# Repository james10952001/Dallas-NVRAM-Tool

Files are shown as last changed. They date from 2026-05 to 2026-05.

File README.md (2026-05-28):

The original intent of this project was to enable bytewise editing of the memory 
and RTC registers of Dallas timekeeping RAM parts used in a lot of older test equipment
such as the DS1644 and DS1742 used in the Tektronix TDS300 and TDS3000 series oscilloscopes.
In the process of implementing that I realized it was trivial to allow reading virtually any
parallel memory device of 32 pins or less and writing to any SRAM or NVRAM so I added support
for other devices I had on hand. 
While it is usually possible to dump the contents of Dallas devices with a TL866 or similar
device programmer, attempting to write to one will stomp on the RTC and status bytes which
can result in the chip's test mode being enabled or other issues. With this you can view and
manipulate individual bytes such as the power on hours of the TDS3000, view and set the 
time/date/day, and activate the test mode while measuring the frequency. I have tried to make
it relatively simple to add support for additional parts and I will try to do so as examples
come into my possession.

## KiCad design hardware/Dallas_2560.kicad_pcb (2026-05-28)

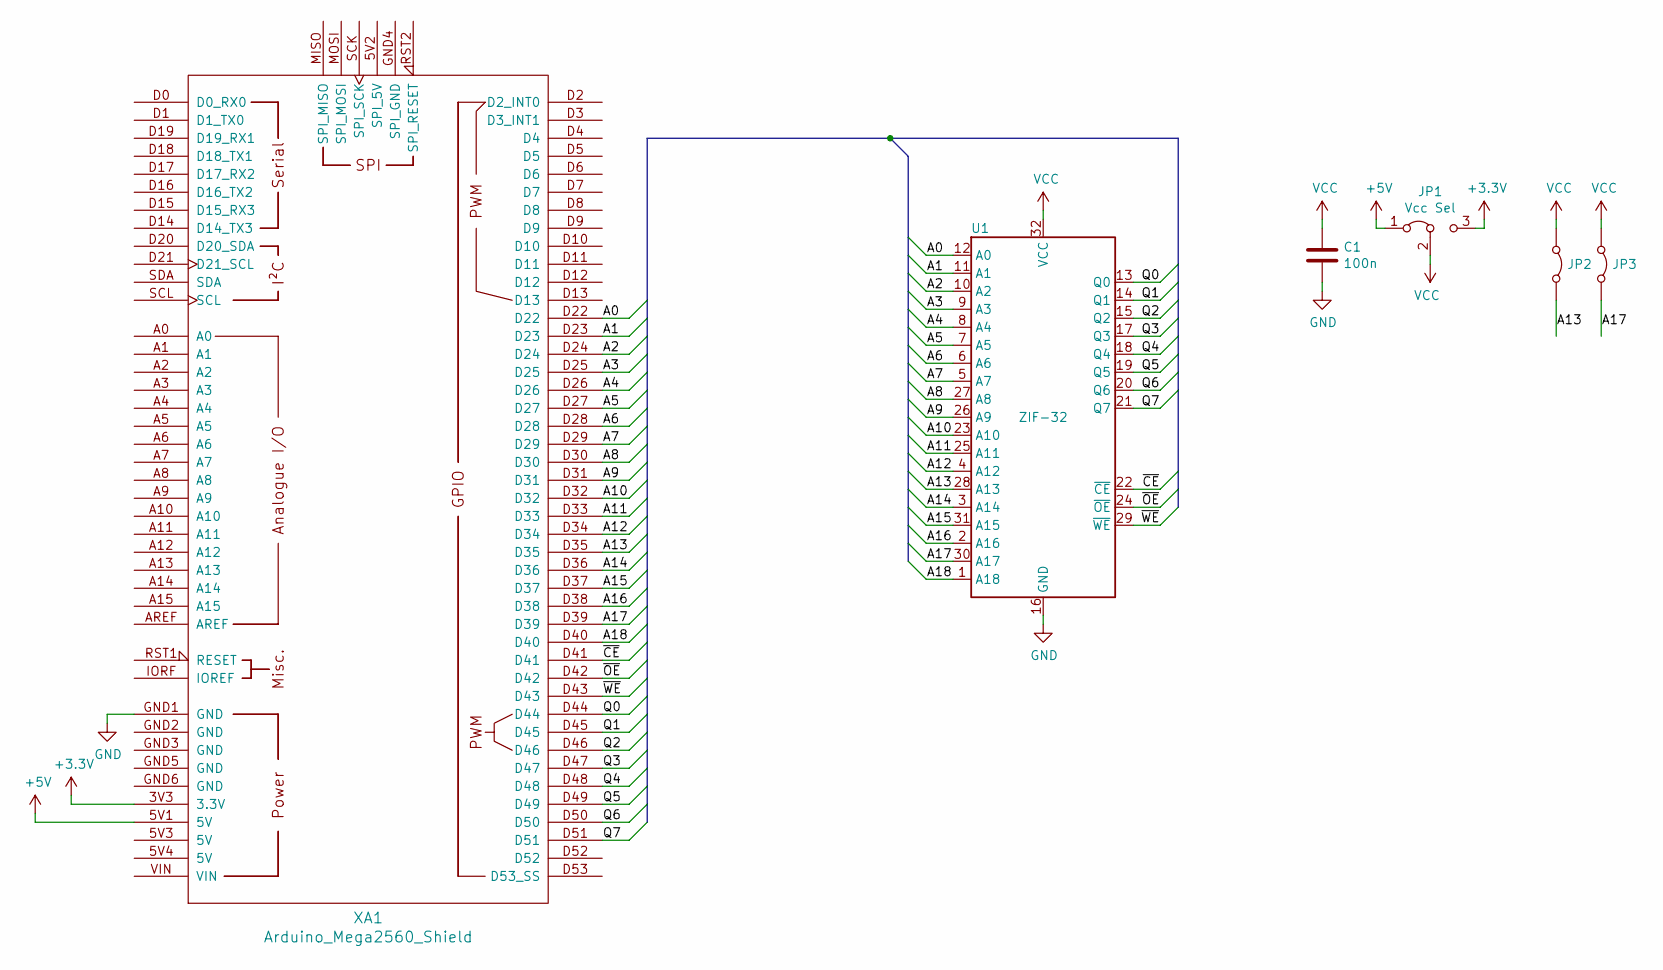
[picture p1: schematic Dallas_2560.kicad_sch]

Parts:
C1: 100n; C_0805_2012Metric
JP1: Vcc Sel; PinHeader_1x03_P2.54mm_Vertical
JP2, JP3: JP; PinHeader_1x02_P2.54mm_Vertical
U1: ZIF-32; DIP_Socket-32_W11.9_W12.7_W15.24_W17.78_W18.5_3M_232-1285-0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
XA1: Arduino_Mega2560_Shield

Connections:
+3V3: JP1.3 (B), XA1.3V3 (3.3V)
+5V: JP1.1 (A), XA1.5V1 (5V)
/A0: U1.12 (A0), XA1.D22
/A1: U1.11 (A1), XA1.D23
/A2: U1.10 (A2), XA1.D24
/A3: U1.9 (A3), XA1.D25
/A4: U1.8 (A4), XA1.D26
/A5: U1.7 (A5), XA1.D27
/A6: U1.6 (A6), XA1.D28
/A7: U1.5 (A7), XA1.D29
/A8: U1.27 (A8), XA1.D30
/A9: U1.26 (A9), XA1.D31
/A10: U1.23 (A10), XA1.D32
/A11: U1.25 (A11), XA1.D33
/A12: U1.4 (A12), XA1.D34
/A13: JP2.2 (B), U1.28 (A13), XA1.D35
/A14: U1.3 (A14), XA1.D36
/A15: U1.31 (A15), XA1.D37
/A16: U1.2 (A16), XA1.D38
/A17: JP3.2 (B), U1.30 (A17), XA1.D39
/A18: U1.1 (A18), XA1.D40
/Q0: U1.13 (Q0), XA1.D44
/Q1: U1.14 (Q1), XA1.D45
/Q2: U1.15 (Q2), XA1.D46
/Q3: U1.17 (Q3), XA1.D47
/Q4: U1.18 (Q4), XA1.D48
/Q5: U1.19 (Q5), XA1.D49
/Q6: U1.20 (Q6), XA1.D50
/Q7: U1.21 (Q7), XA1.D51
/~CE: U1.22 (~CE), XA1.D41
/~OE: U1.24 (~OE), XA1.D42
/~WE: U1.29 (~WE), XA1.D43
GND: C1.2, U1.16 (GND), XA1.GND1 (GND)
VCC: C1.1, JP1.2 (C), JP2.1 (A), JP3.1 (A), U1.32 (VCC)

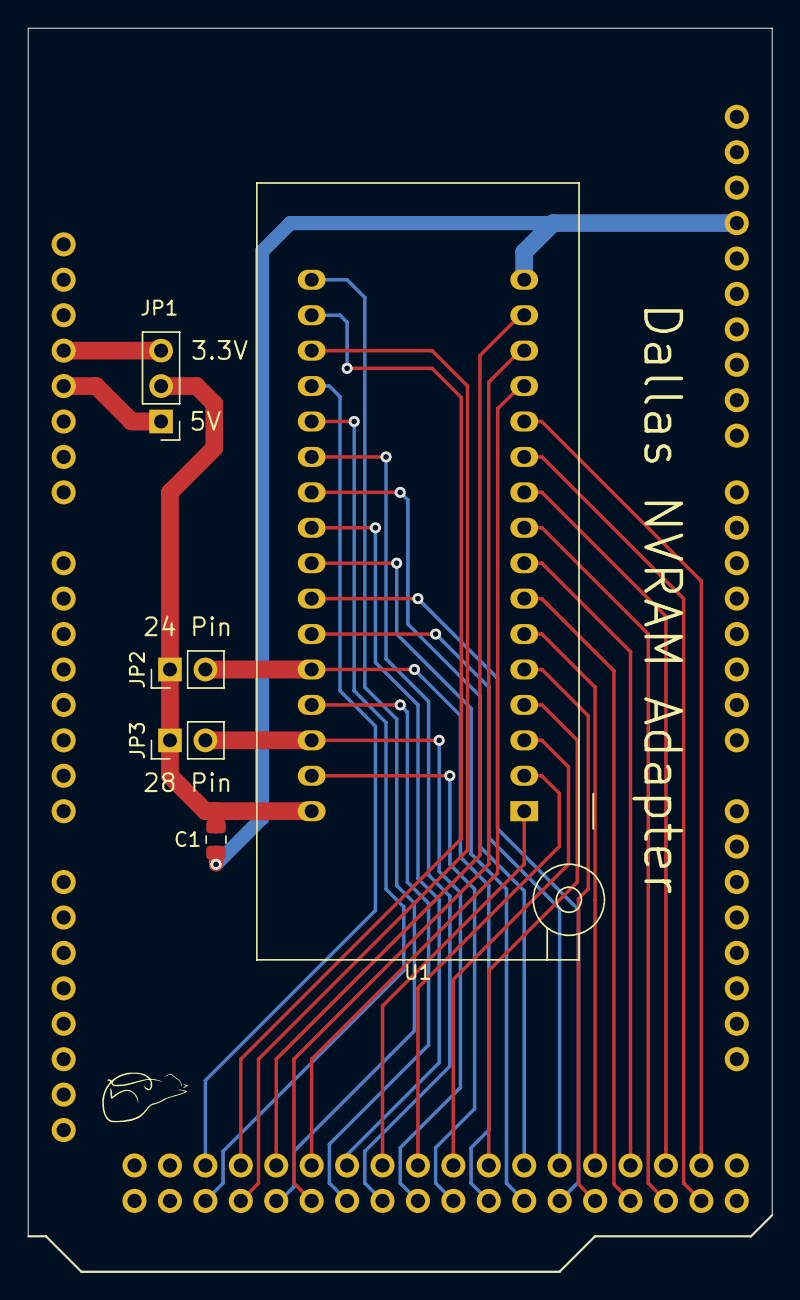
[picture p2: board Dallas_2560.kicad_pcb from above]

Board: 2 copper layers, 53.3 x 89.2 mm, 7 parts (0 on the bottom side), 34 nets.

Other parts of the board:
VAL: REF; cat_300

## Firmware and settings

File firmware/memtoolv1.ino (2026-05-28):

/*
 * Universal NVRAM tool
 *
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
 * You should have received a copy of the GNU General Public License
 * along with this program. If not, see <https://www.gnu.org/licenses/>.
 */

#include <Arduino.h>
#include <EEPROM.h>

const int EEPROM_CONFIG_ADDR = 0;
const int EEPROM_CONFIG_SIZE = 32; // Reserve a generous 32 bytes for future-proofing

// ============================================================
// DEVICE TYPES
// ============================================================

enum DeviceType {
  DEV_GENERIC_24 = 0,
  DEV_GENERIC_28 = 1,
  DEV_GENERIC_32 = 2,
  DEV_DS1742 = 3,
  DEV_DS1644 = 4,
  DEV_KM684000 = 5,
  DEV_MAX // Used strictly for EEPROM boundary validation
};

DeviceType g_device = DEV_DS1742;

// ============================================================
// DYNAMIC PROFILES
// ============================================================

struct PinMap {
  int8_t addr[19]; // Increased from 15 to 19 (A0 - A18) for 512KB chips
  int8_t data[8];  // DQ0 - DQ7
  int8_t ce;
  int8_t oe;
  int8_t we;
  int8_t ce2;      // SECOND Chip Enable (Active HIGH)
};

struct RTCProfile {
  bool hasRTC;
  uint32_t baseAddress; 
  bool hasCentury;     // Does Control register contain Century data?
  bool hasBatteryFlag; // Does Day register contain a Battery Flag?
};

struct DeviceInfo {
  const char* name;
  uint32_t sizeBytes;
  uint32_t protectedStart; 
  RTCProfile rtc;
  PinMap pins;
};

// Global active pin map for fast low-level access
PinMap g_activePins;

// ============================================================
// DEVICE INFO
// ============================================================

// The arduino to 32 pin socket mapping is as follows:
// D40	1
// D38	2
// D36	3
// D34	4
// D29	5
// D28	6
// D27	7
// D26	8
// D25	9
// D24	10
// D23	11
// D22	12
// D44	13
// D45	14
// D46	15
// Gnd	16
// D47	17
// D48	18
// D49	19
// D50	20
// D51	21
// D41	22
// D32	23
// D42	24
// D33	25
// D31	26
// D30	27
// D35	28
// D43	29
// D39	30
// D37	31
// Vcc	32

// Devices smaller than 32 pins are inserted at the lower end of the socket resulting in 
// their pin numbers being offset by 4 for 24 pin devices and 2 for 28 pin devices.


DeviceInfo getDeviceInfo() {
  switch (g_device) {

    case DEV_GENERIC_24:
      return {
        "Generic SRAM/ROM (24 pin)",
        2048,
        0xFFFFFFFF,
        { false, 0, false, false },
        { 
          // A0-A10
          {22, 23, 24, 25, 26, 27, 28, 29, 30, 31, 32, -1, -1, -1, -1, -1, -1, -1, -1}, 
          {44, 45, 46, 47, 48, 49, 50, 51}, 
          41, 42, 33, -1 
        }
      };

    case DEV_GENERIC_28:
      return {
        "Generic SRAM/ROM (28 pin)",
        8192,
        0xFFFFFFFF,
        { false, 0, false, false },
        { 
          // A0-A12
          {22, 23, 24, 25, 26, 27, 28, 29, 30, 31, 32, 33, 34, -1, -1, -1, -1, -1, -1}, 
          {44, 45, 46, 47, 48, 49, 50, 51}, 
          41, 42, 43, 35  // D35 drives CE2 HIGH
        }
      };

    case DEV_GENERIC_32:
      return {
        "Generic SRAM/ROM (32 pin)",
        32768,
        0xFFFFFFFF,
        { false, 0, false, false },
        { 
          // A0-A14
          {22, 23, 24, 25, 26, 27, 28, 29, 30, 31, 32, 33, 34, 35, 36, -1, -1, -1, -1}, 
          {44, 45, 46, 47, 48, 49, 50, 51}, 
          41, 42, 43, -1 
        }
      };

    case DEV_DS1742:
      return {
        "Dallas DS1742",
        2048,
        0x7F8,
        { true, 0x7F8, true, true },
        { 
          // A0-A10
          {22, 23, 24, 25, 26, 27, 28, 29, 30, 31, 32, -1, -1, -1, -1, -1, -1, -1, -1}, 
          {44, 45, 46, 47, 48, 49, 50, 51}, 
          41, 42, 33, -1 
        }
      };

    case DEV_DS1644:
      return {
        "Dallas DS1644",
        32768,
        0x7FF8,
        { true, 0x7FF8, false, false },
        { 
          // A0-A14
          {22, 23, 24, 25, 26, 27, 28, 29, 30, 31, 32, 33, 34, 35, 36, -1, -1, -1, -1}, 
          {44, 45, 46, 47, 48, 49, 50, 51}, 
          41, 42, 43, -1 
        }
      };

    case DEV_KM684000:
      return {
        "Samsung KM684000",
        524288, // 512KB Capacity
        0xFFFFFFFF,
        { false, 0, false, false },
        { 
          // A0-A18 sequential magic!
          {22, 23, 24, 25, 26, 27, 28, 29, 30, 31, 32, 33, 34, 35, 36, 37, 38, 39, 40}, 
          {44, 45, 46, 47, 48, 49, 50, 51}, 
          41, 42, 43, -1 
        }
      };
  }

  // Default fallback (Safe generic 2KB state)
  return {
    "Unknown",
    2048,
    0xFFFFFFFF,
    { false, 0, false, false },
    { 
      {22, 23, 24, 25, 26, 27, 28, 29, 30, 31, 32, -1, -1, -1, -1, -1, -1, -1, -1}, 
      {44, 45, 46, 47, 48, 49, 50, 51}, 
      41, 42, 33, -1 
    }
  };
}

// ============================================================
// RTC BIT DEFINITIONS
// ============================================================

const uint8_t BIT_W   = 0x80;
const uint8_t BIT_R   = 0x40;
const uint8_t BIT_OSC = 0x80;
const uint8_t BIT_FT  = 0x40;
const uint8_t BIT_BF  = 0x80;

// ============================================================
// GLOBALS
// ============================================================

uint8_t g_century = 0;

// ============================================================
// UTILITY FUNCTIONS
// ============================================================

void printHexAddress(uint32_t address) {
  if (address <= 0xFFFF) {
    char buf[5];
    sprintf(buf, "%04lX", address);
    Serial.print(buf);
  } else {
    char buf[9];
    sprintf(buf, "%08lX", address);
    Serial.print(buf);
  }
}

void printHexByte(uint8_t value) {
  if (value < 16) {
    Serial.print('0');
  }
  Serial.print(value, HEX);
}

void print2Digits(uint8_t value) {
  if (value < 10) {
    Serial.print('0');
  }
  Serial.print(value);
}

// ============================================================
// RTC REGISTER HELPERS
// ============================================================

uint32_t regControl() { return getDeviceInfo().rtc.baseAddress + 0; }
uint32_t regSeconds() { return getDeviceInfo().rtc.baseAddress + 1; }
uint32_t regMinutes() { return getDeviceInfo().rtc.baseAddress + 2; }
uint32_t regHours()   { return getDeviceInfo().rtc.baseAddress + 3; }
uint32_t regDay()     { return getDeviceInfo().rtc.baseAddress + 4; }
uint32_t regDate()    { return getDeviceInfo().rtc.baseAddress + 5; }
uint32_t regMonth()   { return getDeviceInfo().rtc.baseAddress + 6; }
uint32_t regYear()    { return getDeviceInfo().rtc.baseAddress + 7; }

// ============================================================
// LOW LEVEL BUS FUNCTIONS
// ============================================================

void applyPinConfiguration() {
  // 1. Reset standard socket pins to INPUT (High-Z) to prevent shorts
  for(uint8_t i = 22; i <= 53; i++) {
     pinMode(i, INPUT);
  }

  // 2. Load the active pin map
  g_activePins = getDeviceInfo().pins;

// 3. Configure Address pins
  for (uint8_t i = 0; i < 19; i++) { // <-- Change to 19
    if (g_activePins.addr[i] != -1) {
      pinMode(g_activePins.addr[i], OUTPUT);
      digitalWrite(g_activePins.addr[i], LOW);
    }
  }

  // 4. Configure Control pins
  pinMode(g_activePins.ce, OUTPUT);
  pinMode(g_activePins.oe, OUTPUT);
  pinMode(g_activePins.we, OUTPUT);
  
  if (g_activePins.ce2 != -1) {
    pinMode(g_activePins.ce2, OUTPUT);
    digitalWrite(g_activePins.ce2, HIGH); // CE2 is active HIGH
  }

  // 5. Secure the bus
  busIdle();
  setDataBusInput();
}

void busIdle() {
  digitalWrite(g_activePins.ce, HIGH);
  digitalWrite(g_activePins.oe, HIGH);
  digitalWrite(g_activePins.we, HIGH);
}

void setAddress(uint32_t address) {
  for (uint8_t i = 0; i < 19; i++) { // <-- Change to 19
    if (g_activePins.addr[i] != -1) {
      digitalWrite(g_activePins.addr[i], (address >> i) & 1);
    }
  }
}

void setDataBusInput() {
  for (uint8_t i = 0; i < 8; i++) {
    pinMode(g_activePins.data[i], INPUT);
  }
}

void setDataBusOutput() {
  for (uint8_t i = 0; i < 8; i++) {
    pinMode(g_activePins.data[i], OUTPUT);
  }
}

void writeDataBus(uint8_t value) {
  for (uint8_t i = 0; i < 8; i++) {
    digitalWrite(g_activePins.data[i], (value >> i) & 1);
  }
}

uint8_t readDataBus() {
  uint8_t value = 0;
  for (uint8_t i = 0; i < 8; i++) {
    if (digitalRead(g_activePins.data[i])) {
      value |= (1 << i);
    }
  }
  return value;
}

// ============================================================
// RAW MEMORY ACCESS
// ============================================================

uint8_t readByteRaw(uint32_t address) {
  busIdle();
  setAddress(address);
  setDataBusInput();
  delayMicroseconds(1);
  digitalWrite(g_activePins.ce, LOW);
  digitalWrite(g_activePins.oe, LOW);
  delayMicroseconds(2);
  uint8_t value = readDataBus();
  busIdle();
  return value;
}

void writeByteRaw(uint32_t address, uint8_t value) {
  busIdle();
  setAddress(address);
  digitalWrite(g_activePins.oe, HIGH);
  setDataBusOutput();
  writeDataBus(value);
  delayMicroseconds(1);
  digitalWrite(g_activePins.ce, LOW);
  delayMicroseconds(1);
  digitalWrite(g_activePins.we, LOW);
  delayMicroseconds(2);
  digitalWrite(g_activePins.we, HIGH);
  busIdle();
  setDataBusInput();
}

// ============================================================
// RTC HELPERS
// ============================================================

bool requireRTC() {
  if (!getDeviceInfo().rtc.hasRTC) {
    Serial.println(F("Selected device has no RTC."));
    return false;
  }
  return true;
}

uint8_t bcdToDec(uint8_t value) {
  return ((value >> 4) * 10) + (value & 0x0F);
}

uint8_t decToBcd(uint8_t value) {
  return ((value / 10) << 4) | (value % 10);
}

void rtcBeginRead() {
  DeviceInfo info = getDeviceInfo();
  if (!info.rtc.hasRTC) return;

  uint8_t control = readByteRaw(regControl());
  
  if (info.rtc.hasCentury) {
    g_century = control & 0x3F;
    writeByteRaw(regControl(), BIT_R | g_century);
  } else {
    writeByteRaw(regControl(), BIT_R);
  }
}

void rtcEndRead() {
  DeviceInfo info = getDeviceInfo();
  if (!info.rtc.hasRTC) return;

  if (info.rtc.hasCentury) {
    writeByteRaw(regControl(), g_century);
  } else {
    writeByteRaw(regControl(), 0);
  }
  delayMicroseconds(600);
}

void rtcBeginWrite() {
  DeviceInfo info = getDeviceInfo();
  if (!info.rtc.hasRTC) return;

  uint8_t control = readByteRaw(regControl());
  
  if (info.rtc.hasCentury) {
    g_century = control & 0x3F;
    writeByteRaw(regControl(), BIT_W | g_century);
  } else {
    writeByteRaw(regControl(), BIT_W);
  }
}

void rtcEndWrite() {
  DeviceInfo info = getDeviceInfo();
  if (!info.rtc.hasRTC) return;

  if (info.rtc.hasCentury) {
    writeByteRaw(regControl(), g_century);
  } else {
    writeByteRaw(regControl(), 0);
  }
}

// ============================================================
// SERIAL HELPERS
// ============================================================

String readLine() {
  String s = "";
  while (true) {
    while (!Serial.available()) {}
    char c = Serial.read();
    if (c == '\r' || c == '\n') {
      Serial.println();
      break;
    }
    if ((c == 8 || c == 127) && s.length() > 0) {
      s.remove(s.length() - 1);
      Serial.print(F("\b \b"));
      continue;
    }
    Serial.print(c);
    s += c;
  }
  s.trim();
  s.toUpperCase();
  return s;
}

bool parseHex32(String s, uint32_t &value) {
  char *endptr;
  unsigned long v = strtoul(s.c_str(), &endptr, 16);
  if (*endptr != '\0') return false;
  value = v;
  return true;
}

bool parseHex8(String s, uint8_t &value) {
  char *endptr;
  unsigned long v = strtoul(s.c_str(), &endptr, 16);
  if (*endptr != '\0') return false;
  if (v > 0xFF) return false;
  value = (uint8_t)v;
  return true;
}

// ============================================================
// INTEL HEX HELPERS
// ============================================================

uint8_t intelHexChecksum(uint8_t count, uint16_t address, uint8_t type, const uint8_t* data) {
  uint8_t sum = 0;
  sum += count;
  sum += (address >> 8) & 0xFF;
  sum += address & 0xFF;
  sum += type;
  for (uint8_t i = 0; i < count; i++) {
    sum += data[i];
  }
  return (uint8_t)(0 - sum);
}

uint8_t hexDigit(char c) {
  if (c >= '0' && c <= '9') return c - '0';
  if (c >= 'A' && c <= 'F') return c - 'A' + 10;
  if (c >= 'a' && c <= 'f') return c - 'a' + 10;
  return 0;
}

uint8_t parseHexByte(const String &s, int index) {
  return (hexDigit(s[index]) << 4) | hexDigit(s[index + 1]);
}

// ============================================================
// DEVICE SELECTION
// ============================================================

void handleSelectDevice() {
  Serial.println();
  Serial.println(F("SELECT DEVICE"));
  Serial.println();
  Serial.println(F("A. Generic SRAM/ROM (24 pin)"));
  Serial.println(F("B. Generic SRAM/ROM (28 pin)"));
  Serial.println(F("C. Generic SRAM/ROM (32 pin)"));
  Serial.println(F("D. Dallas DS1742"));
  Serial.println(F("E. Dallas DS1644"));
  Serial.println(F("F. Samsung KM684000"));
  Serial.println();
  Serial.print(F("Selection: "));
  
  String s = readLine();
  switch (s.charAt(0)) {
    case 'A': g_device = DEV_GENERIC_24; break;
    case 'B': g_device = DEV_GENERIC_28; break;
    case 'C': g_device = DEV_GENERIC_32; break;
    case 'D': g_device = DEV_DS1742; break;
    case 'E': g_device = DEV_DS1644; break;
    case 'F': g_device = DEV_KM684000; break;
    default:
      Serial.println(F("INVALID"));
      return;
  }
  
  // Wipe and save the new selection to EEPROM
  saveDeviceToEEPROM();
  
  // Reconfigure the hardware for the newly selected device
  applyPinConfiguration();

  Serial.println();
  Serial.print(F("Selected: "));
  Serial.println(getDeviceInfo().name);
}


// ============================================================
// READ BYTE
// ============================================================

void handleReadByte() {
  Serial.println();
  Serial.println(F("READ BYTE"));
  Serial.print(F("Address HEX: "));
  
  uint32_t address;
  if (!parseHex32(readLine(), address)) {
    Serial.println(F("INVALID"));
    return;
  }
  
  uint8_t value = readByteRaw(address);
  Serial.println();
  Serial.print(F("HEX: 0x"));
  printHexByte(value);
  Serial.println();
  Serial.print(F("DEC: "));
  Serial.println(value);
  Serial.print(F("BIN: "));
  
  for (int i = 7; i >= 0; i--) {
    Serial.print((value >> i) & 1);
    if (i == 4) Serial.print(' ');
  }
  Serial.println();
}

// ============================================================
// WRITE BYTE
// ============================================================

void handleWriteByte() {
  Serial.println();
  Serial.println(F("WRITE BYTE"));
  Serial.print(F("Address HEX: "));
  
  uint32_t address;
  if (!parseHex32(readLine(), address)) {
    Serial.println(F("INVALID"));
    return;
  }
  
  Serial.print(F("Data HEX: "));
  uint8_t value;
  if (!parseHex8(readLine(), value)) {
    Serial.println(F("INVALID"));
    return;
  }
  
  writeByteRaw(address, value);
  uint8_t verify = readByteRaw(address);
  Serial.print(F("Verify: 0x"));
  printHexByte(verify);
  Serial.println();
}

// ============================================================
// DUMP MEMORY RAW
// ============================================================

void handleDumpMemory() {
  DeviceInfo info = getDeviceInfo();
  uint32_t startAddr = 0;
  uint32_t endAddr = info.sizeBytes - 1;
  
  Serial.println();
  Serial.println(F("DUMP MEMORY"));
  Serial.println();
  Serial.print(F("Start Address HEX (default 0000): "));
  
  String s = readLine();
  if (s.length() > 0) {
    if (!parseHex32(s, startAddr)) {
      Serial.println(F("INVALID"));
      return;
    }
  }
  
  Serial.print(F("End Address HEX (default "));
  printHexAddress(endAddr);
  Serial.print(F("): "));
  
  s = readLine();
  if (s.length() > 0) {
    if (!parseHex32(s, endAddr)) {
      Serial.println(F("INVALID"));
      return;
    }
  }
  
  if (startAddr >= info.sizeBytes || endAddr >= info.sizeBytes || endAddr < startAddr) {
    Serial.println(F("INVALID RANGE"));
    return;
  }
  
  Serial.println();
  Serial.println(F("DUMP"));
  Serial.println();
  
  for (uint32_t addr = startAddr; addr <= endAddr; addr += 16) {
    printHexAddress(addr);
    Serial.print(F(": "));
    
    for (uint8_t i = 0; i < 16; i++) {
      uint32_t current = addr + i;
      if (current > endAddr) {
        Serial.print(F("   "));
        continue;
      }
      printHexByte(readByteRaw(current));
      Serial.print(' ');
    }
    
    Serial.print(F(" "));
    for (uint8_t i = 0; i < 16; i++) {
      uint32_t current = addr + i;
      if (current > endAddr) break;
      uint8_t value = readByteRaw(current);
      if (value >= 32 && value <= 126) {
        Serial.print((char)value);
      } else {
        Serial.print('.');
      }
    }
    Serial.println();
    if (addr + 16 < addr) break;
  }
  Serial.println();
}

// ============================================================
// DUMP TO INTEL HEX
// ============================================================

void handleDumpHex() {
  DeviceInfo info = getDeviceInfo();
  uint32_t endAddr = info.sizeBytes - 1;
  
  Serial.println();
  Serial.println(F("DUMP TO INTEL HEX"));
  Serial.println();
  Serial.print(F("End Address HEX (default "));
  printHexAddress(endAddr);
  Serial.print(F("): "));
  
  String s = readLine();
  if (s.length() > 0) {
    if (!parseHex32(s, endAddr)) {
      Serial.println(F("INVALID"));
      return;
    }
  }
  
  if (endAddr >= info.sizeBytes) {
    Serial.println(F("INVALID RANGE"));
    return;
  }
  
  Serial.println();
  Serial.println(F("BEGIN INTEL HEX"));
  Serial.println();
  
  uint8_t data[16];
  uint32_t addr = 0;
  
  while (addr <= endAddr) {
    uint8_t count = 16;
    if ((addr + count - 1) > endAddr) {
      count = (endAddr - addr) + 1;
    }
    
    for (uint8_t i = 0; i < count; i++) {
      data[i] = readByteRaw(addr + i);
    }
    
    uint16_t lineAddr = addr & 0xFFFF;
    uint8_t checksum = intelHexChecksum(count, lineAddr, 0x00, data);
    
    Serial.print(':');
    printHexByte(count);
    char buf[5];
    sprintf(buf, "%04X", lineAddr);
    Serial.print(buf);
    Serial.print(F("00"));
    
    for (uint8_t i = 0; i < count; i++) {
      printHexByte(data[i]);
    }
    printHexByte(checksum);
    Serial.println();
    addr += count;
  }
  
  Serial.println(F(":00000001FF"));
  Serial.println();
  Serial.println(F("END INTEL HEX"));
}

// ============================================================
// PROGRAM FROM INTEL HEX
// ============================================================

void handleProgramHex() {
  DeviceInfo info = getDeviceInfo();
  Serial.println();
  Serial.println(F("PROGRAM FROM INTEL HEX"));
  Serial.println();
  Serial.println(F("Paste Intel HEX records."));
  Serial.println(F("Send EOF record (:00000001FF) to finish."));
  Serial.println();
  
  Serial.setTimeout(2000);
  while (Serial.available()) {
    Serial.read();
  }
  
  uint32_t lines = 0;
  uint32_t bytesWritten = 0;
  uint32_t bytesSkipped = 0;
  
  while (true) {
    String line = Serial.readStringUntil('\n');
    line.trim();
    line.toUpperCase();
    
    if (line.length() == 0) continue;
    if (line.charAt(0) != ':') {
      Serial.println(F("INVALID RECORD"));
      continue;
    }
    
    if (line == ":00000001FF") {
      Serial.println();
      Serial.println(F("IMPORT COMPLETE"));
      Serial.print(F("Lines: "));
      Serial.println(lines);
      Serial.print(F("Bytes Written: "));
      Serial.println(bytesWritten);
      Serial.print(F("Bytes Skipped: "));
      Serial.println(bytesSkipped);
      return;
    }
    
    if (line.length() < 11) {
      Serial.println(F("SHORT RECORD"));
      continue;
    }
    
    uint8_t count = parseHexByte(line, 1);
    uint16_t address = ((uint16_t)parseHexByte(line, 3) << 8) | parseHexByte(line, 5);
    uint8_t type = parseHexByte(line, 7);
    
    if (type != 0x00) continue;
    
    uint16_t expectedLength = 11 + (count * 2);
    if (line.length() < expectedLength) {
      Serial.println(F("TRUNCATED RECORD"));
      continue;
    }
    
    uint8_t sum = 0;
    for (uint16_t i = 1; i < (9 + count * 2); i += 2) {
      sum += parseHexByte(line, i);
    }
    uint8_t checksum = parseHexByte(line, 9 + (count * 2));
    sum += checksum;
    
    if (sum != 0) {
      Serial.println(F("CHECKSUM ERROR"));
      continue;
    }
    
    for (uint8_t i = 0; i < count; i++) {
      uint32_t addr = address + i;
      if (addr >= info.sizeBytes) continue;
      
      if (info.rtc.hasRTC && addr >= info.protectedStart) {
        bytesSkipped++;
        continue;
      }
      
      uint8_t value = parseHexByte(line, 9 + (i * 2));
      writeByteRaw(addr, value);
      bytesWritten++;
    }
    
    lines++;
    if ((lines & 0x3F) == 0) {
      Serial.print('.');
    }
  }
}

// ============================================================
// CLEAR MEMORY
// ============================================================
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
void loop() {
  showMenu();
  String selection = readLine();
  
  if (selection.length() == 0) return;
  
  switch (selection.charAt(0)) {
    case 'S': handleSelectDevice(); break;
    case 'R': handleReadByte(); break;
    case 'W': handleWriteByte(); break;
    case 'M': handleDumpMemory(); break;
    case 'H': handleDumpHex(); break;
    case 'P': handleProgramHex(); break;
    case 'C': handleClearMemory(); break;
    case 'T': handleRTCStatus(); break;
    case 'I': handleSetTime(); break;
    case 'A': handleSetDate(); break;
    case 'Y': handleSetDay(); break;
    case 'F': handleFrequencyTest(); break;
    default:
      Serial.println(F("INVALID OPTION"));
      break;
  }
}

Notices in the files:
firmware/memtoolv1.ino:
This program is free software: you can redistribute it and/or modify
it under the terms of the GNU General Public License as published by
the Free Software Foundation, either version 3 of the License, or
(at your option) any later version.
